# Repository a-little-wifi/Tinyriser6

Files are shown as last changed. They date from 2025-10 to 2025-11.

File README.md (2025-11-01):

# Tinyriser Hex (Tinyriser6)
Tinyriser for the Tiny6 and Tiny7 generation of Lenovo Tiny PCs
Same idea as [the original Tinyriser](https://github.com/a-little-wifi/Tinyriser), but for the next gen.  
Compatible with M90q gen 1 & 2, P340 and P350 Tiny (M70q and M80q don't have the riser slot populated)

## Features:

- PCIe x16 slot (8 lanes from CPU)
- M.2 M-key NVMe slot (4 lanes from PCH)
- USB 2.0 port
- Fan header
- Other random riser slot IO breakout (for science)
- Plug and play, no mainboard modification necessary

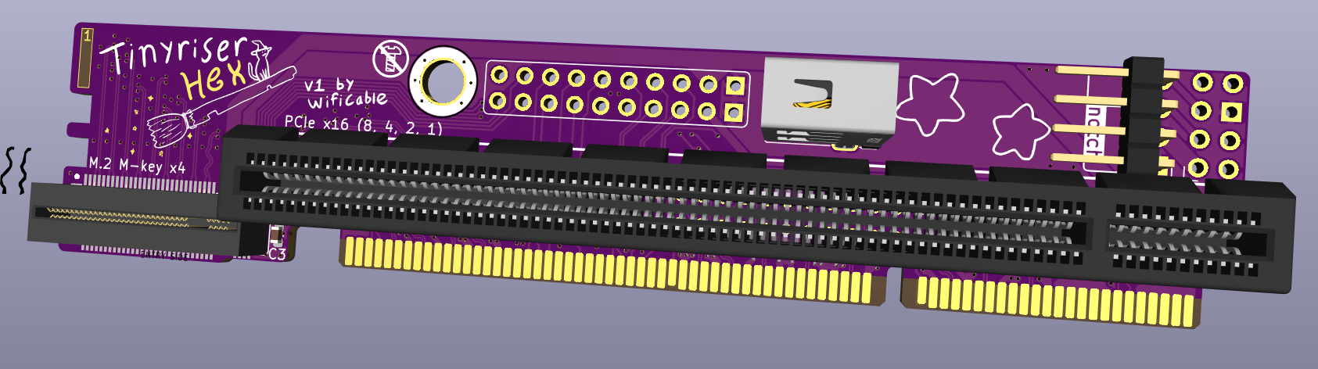
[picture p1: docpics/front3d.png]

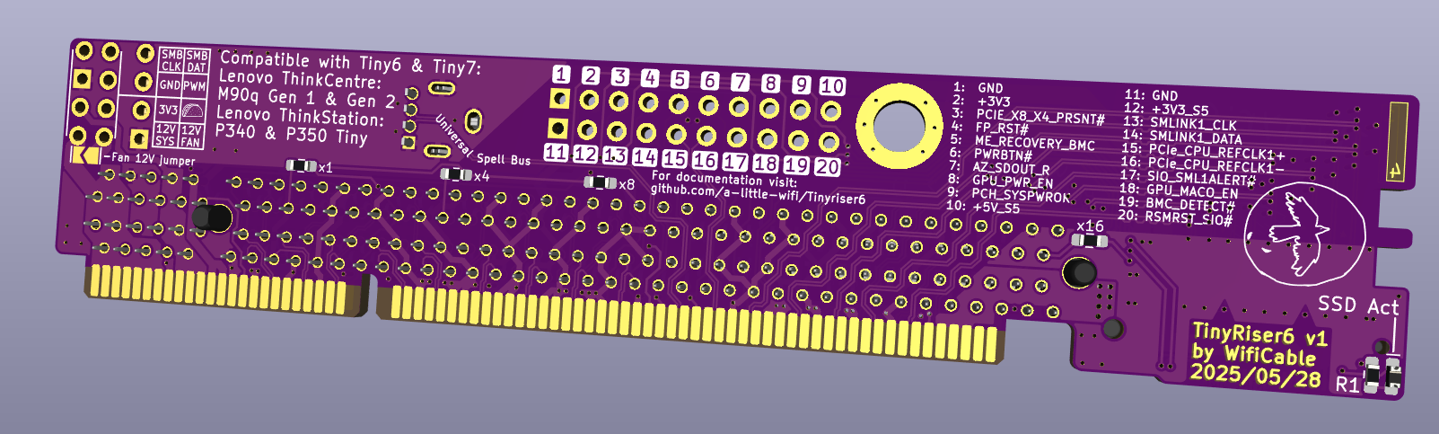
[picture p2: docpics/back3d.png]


> front and back in 3D render  

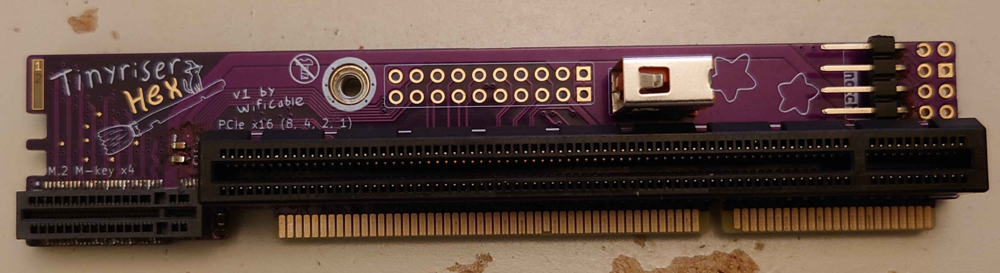
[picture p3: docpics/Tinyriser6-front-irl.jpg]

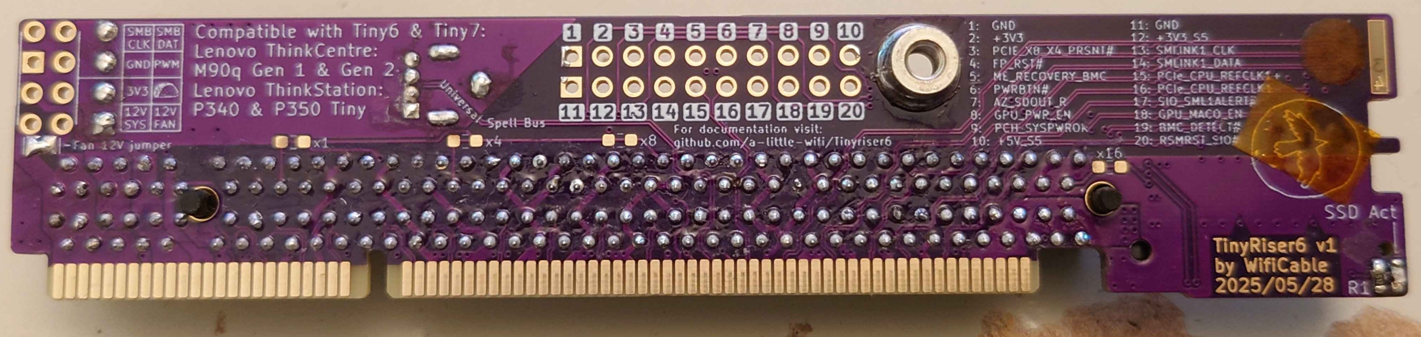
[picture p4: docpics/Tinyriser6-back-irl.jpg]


> front and back in real life

This riser gives you access to the PCIe x8 link from the CPU and the PCIe x4 link from the PCH at the same time, in the form of a PCIe x16 (physical) slot and an M.2 M-key slot.  
Also has a USB 2.0 port because the riser slot has it so why not.  
It does not require any modification to the motherboard of the host machine, just plug and play.  

Using this riser, you can install a low profile PCIe card just as you can with the stock risers, and add an extra M.2 NVMe SSD in addition to the onboard ones. The SSD is tucked away near the front of the machine, plugged into a right angle M-key M.2 slot that holds the SSD firmly in place.  
M.2 2280 length SSDs might have some trouble fitting, especially in combination with longer PCIe cards as they run into the fan and speaker connector on the motherboard. I leave it up to the individual to judge what will be a good fit.  

I've successfully tested this design in P340 (Tiny6) and P350 (Tiny7) machines. Both PCIe links with all lanes as well as the USB port are fully functional in both of them.  

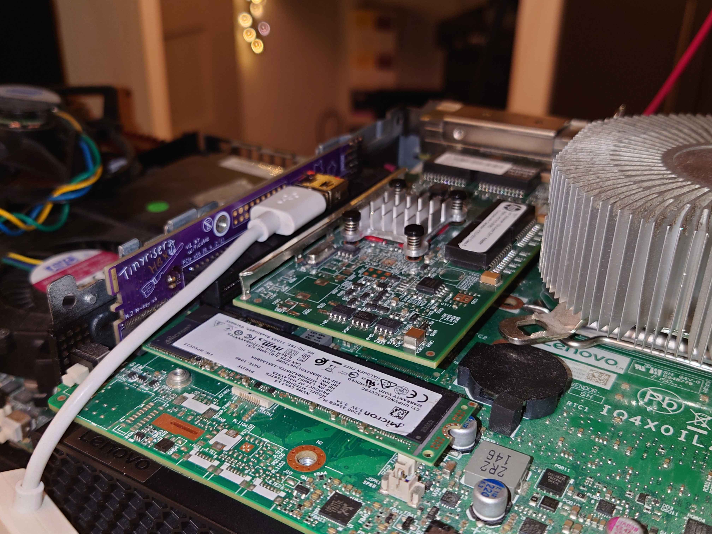
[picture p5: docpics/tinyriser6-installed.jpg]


> riser installed in a P340 with PCIe card, SSD and USB cable attached

### Fan header:
The fan header has the same 3 modes as on the original Tinyriser:
- 12V no PWM
- 12V with PWM
- Voltage controlled speed

The last 2 modes require some kind of fan controller module plugged into the provided header. This has not been designed yet, but the possibility exists.

**Update: v1.1 now has a '5V no PWM' mode available as well, adding an extra jumper from the 5V rail instead of the 12V rail. This 5V rail is always on though, so the fan would be powered even when the system is turned off.**  
**Also be careful when soldering the 5V jumper, it's really close to a 12V pin from the PCIe slot.**

## Thank you

I want to say thank you to everyone for the kind words about my first riser design, I never expected it to reach so far and get so much interest. I originally made it just because I wanted to know if it would work and because I needed a riser for my M720q anyway (would you believe I don't own or have even ever seen a stock Lenovo Tiny5 riser?).  
The experience has had its ups and downs, it turned out I was nowhere near prepared to be handling sales, there's been a few people trying to take credit for my work, and life has been throwing one thing after the other at me, there've been many times I felt bad about it (sorry for the occasional blunt or delayed replies), but in the end I'm still glad I could put it out there and that people have been able to enjoy it. I've even had people reach out suggesting different riser versions and requesting assistance with making modified designs, that's what I love to see. I hope the same will go for this one.

So really, thank you to everyone who has expressed their appreciation for my work, and maybe even bought one from me directly during the short time that was possible. Your support really fills my little wifi heart with motivation to continue making my silly pieces of PCB art in my own way. I hope to keep delving into the depths of modern PC hardware architecture and to deliver more high quality designs with some soul of their own in the future.

This design is the result of everything I've learned from my experience with the original Tinyariser and more. It includes an improved edge connector design that better follows industry standards, a short-circuit discouragement pictogram, several hidden cats, silly puns and more magic.

### Made with ❤ and ✨ by Wifi. I poured my heart, soul and passion into this, I hope you love it too!

## Parts list: 
| part | model | link |
|---|---|---|
| PCIe slot | UMAX 3183-10203P1T | https://www.lcsc.com/product-detail/Card-Edge-Connectors_UMAX-3183-10203P1T_C404116.html |
| Vertical M-key slot | Lotes APCI0110-P001A | (available on aliexpress) |
| Alt M-key slot | HOAUC HYCW19M-05NGFF-530B | https://jlcpcb.com/partdetail/HOAUC-HYCW19M_05NGFF530B/C41430861 (out of stock, but should work with JLC assmebly?) |
| Screwpost | YIYUAN SMTSOM340BTR | https://www.lcsc.com/product-detail/Other-nuts_YIYUAN-SMTSOM340BTR_C5301786.html |
| USB port | Jing 906-862A1118D10200 | https://www.lcsc.com/product-detail/C2763236.html (Warning: EasyEDA footprint pinout is reversed)|

## JLC PCB ordering details:

Please use the files from the v1 release, the main repo might be in the middle of version changes

You're welcome to place your own group orders if you know enough people who are interested in getting one of these risers, however please leave actual selling of this riser design to me and people I've specifically made agreements with.

### Order it in purple Ò̶̖͗̅Ŕ̵͈ ̴̠̬̝̚E̷̖̘̐́̿L̴̢͉̠̕͝S̵͖̺̰̋̀Ē̶̫̾ͅ

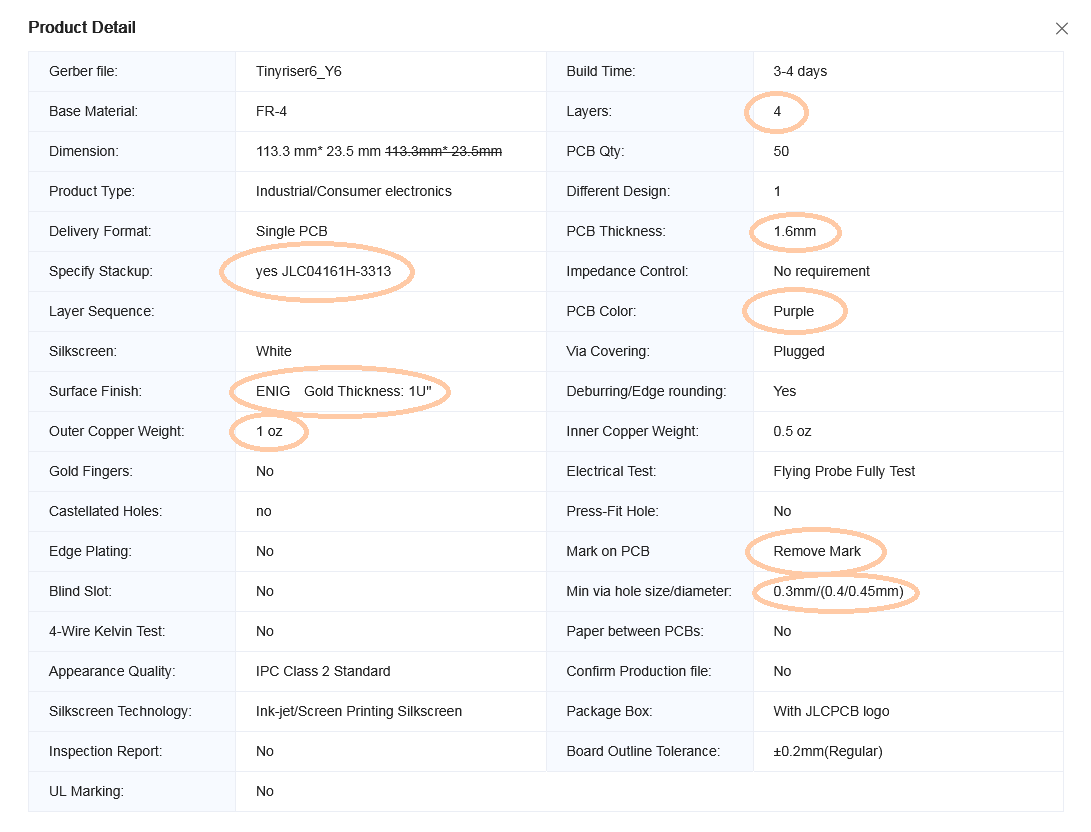
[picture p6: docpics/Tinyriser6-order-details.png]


> Screenshot of the JLC PCB order settings used for Tinyriser6

# Attribution
If you distribute this design or use this design to create a derivative design, you must keep attribution to this original design, in addition to following the terms in the license

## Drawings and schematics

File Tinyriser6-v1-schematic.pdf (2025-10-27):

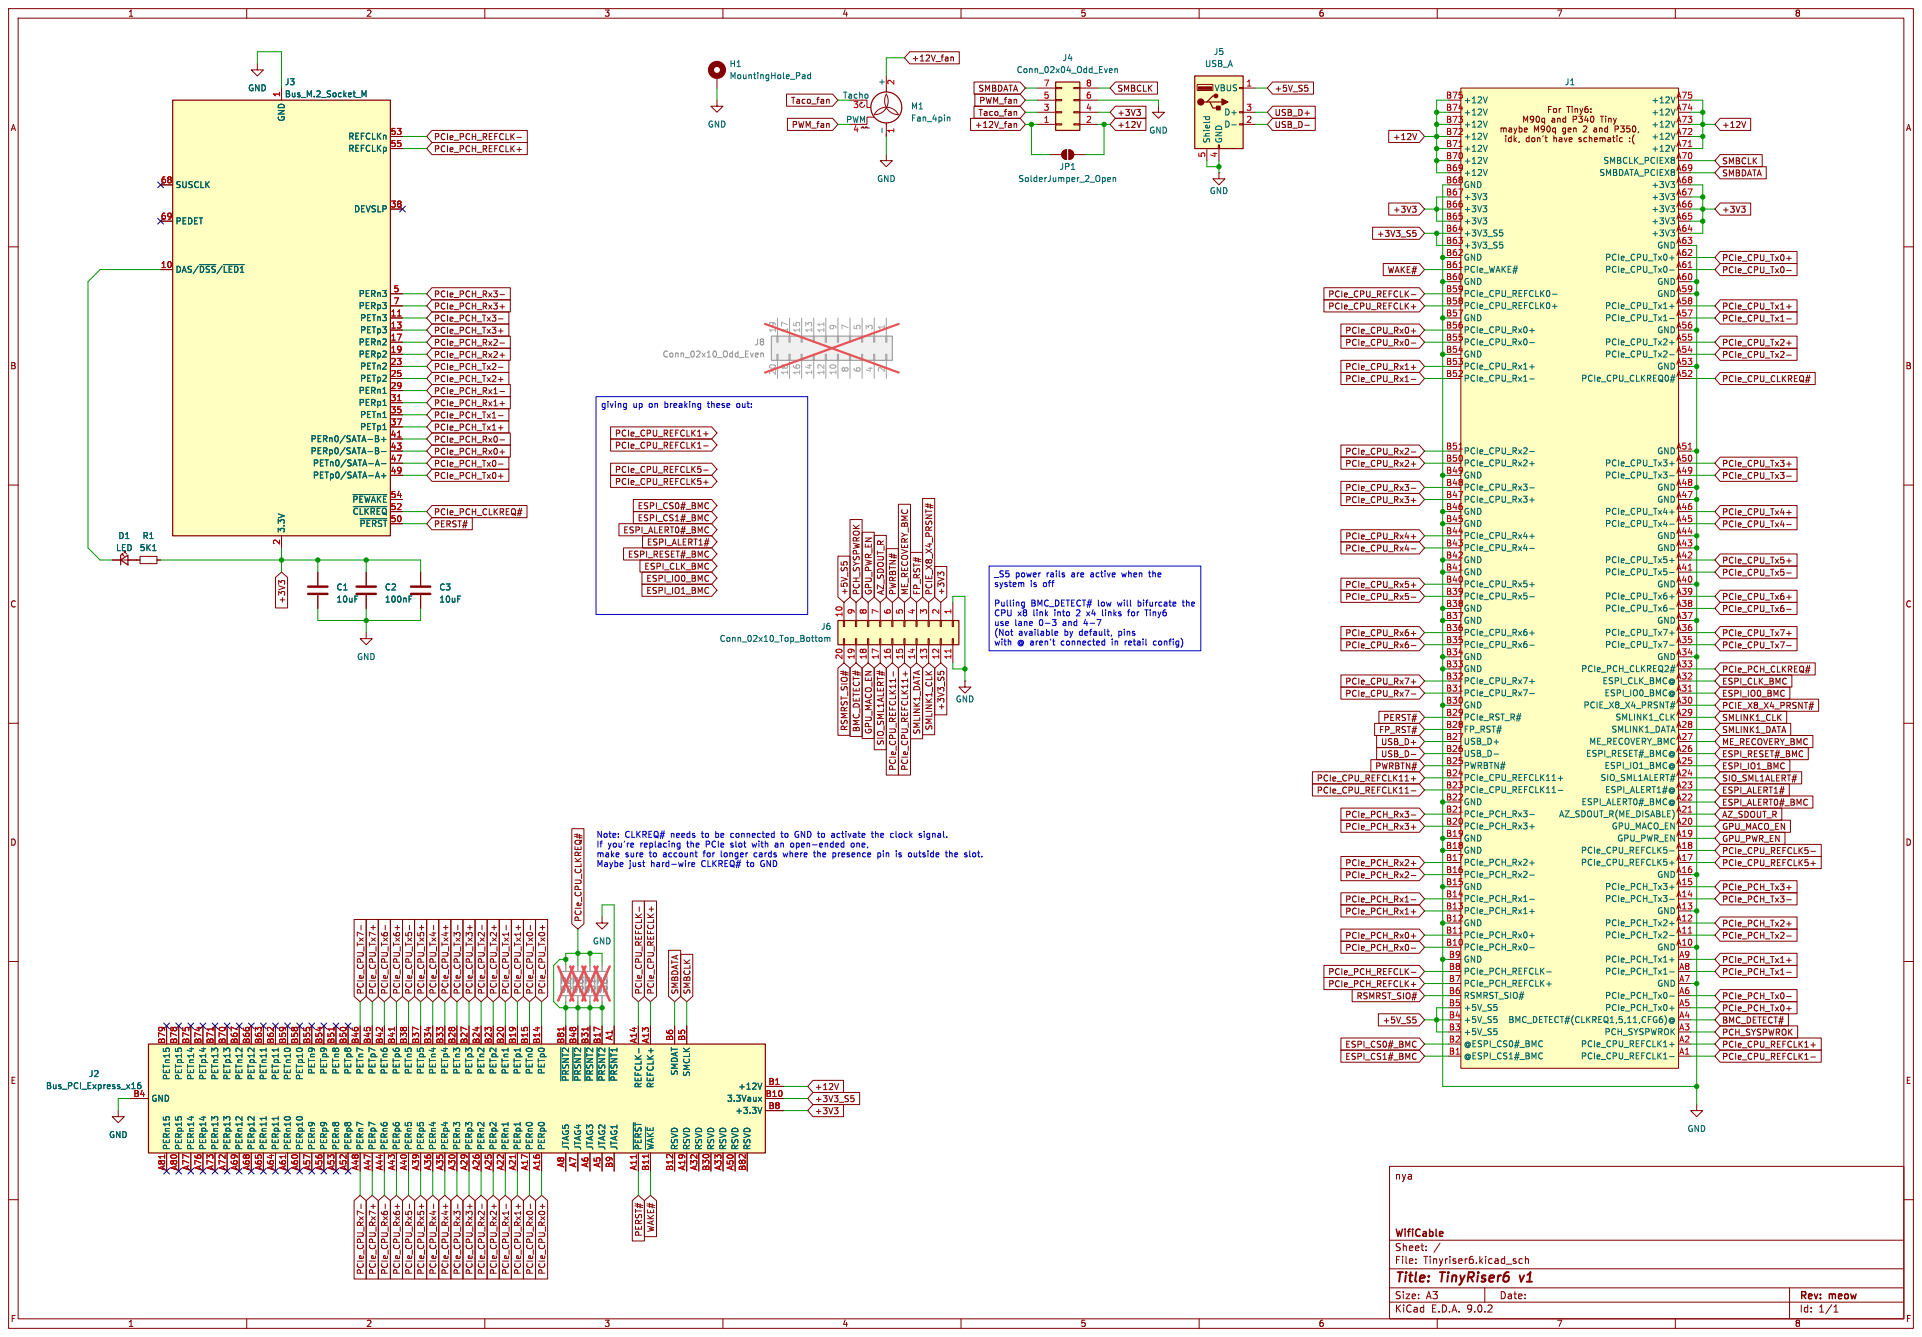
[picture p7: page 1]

1 DAS/~{DSS}/~{LED1} 10 PEDET 69 SUSCLK 68 GND

1 DAS/~{DSS}/~{LED1} 10 PEDET 69 SUSCLK 68

GND SMCLK B5 SMDAT B6 REFCLK+ A13 REFCLK- A14 ~{PRSNT1}A1 ~{PRSNT2}B17 ~{PRSNT2}B31 ~{PRSNT2}B48 ~{PRSNT2}B81 PETp0 B14 PETn0 B15 PETp1 B19 PETn1 B20 PETp2 B23 PETn2 B24 PETp3 B27 PETn3 B28 PETp4 B33 PETn4 B34 PETp5 B37 PETn5 B38 PETp6 B41 PETn6 B42 PETp7 B45 PETn7 B46 PETp8 B50 PETn8 B51 PETp9 B54 PETn9 B55 PETp10 B58 PETn10 B59 PETp11 B62 PETn11 B63 PETp12 B66 PETn12 B67 PETp13 B70 PETn13 B71 PETp14 B74 PETn14 B75 PETp15 B78 PETn15 B79

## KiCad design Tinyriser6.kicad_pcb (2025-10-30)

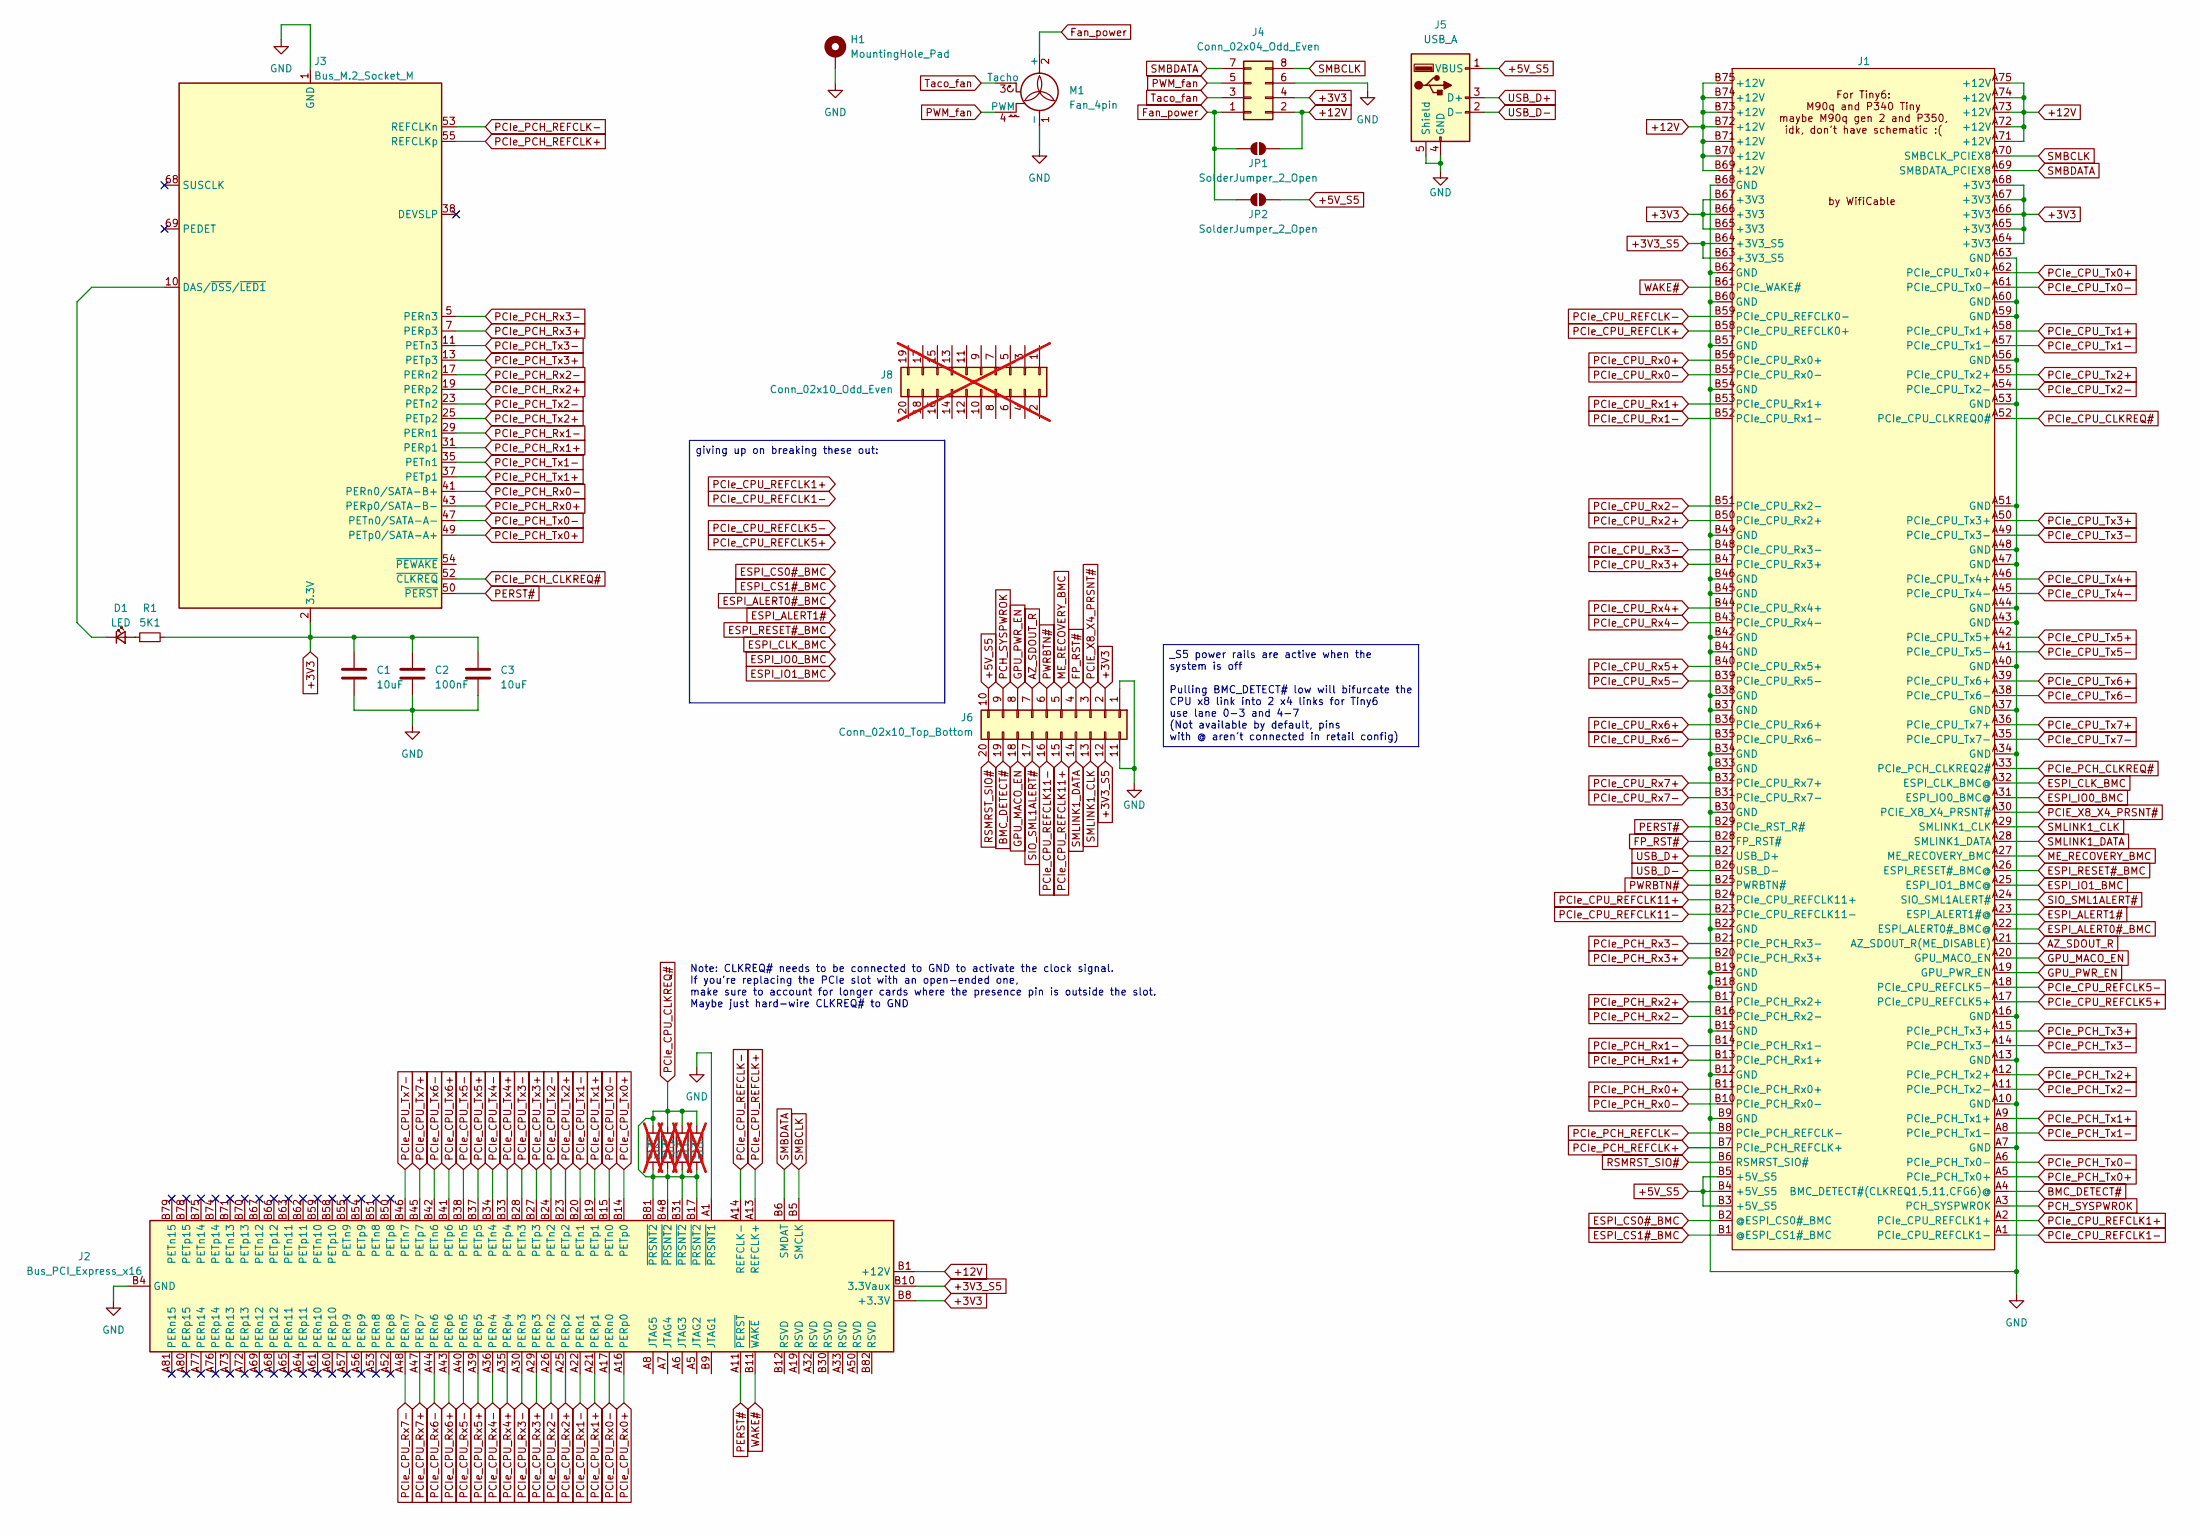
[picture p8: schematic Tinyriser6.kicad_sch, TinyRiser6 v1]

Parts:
C1, C3: 10uF; C_0603_1608Metric
C2: 100nF; C_0603_1608Metric
D1: LED; D_0603_1608Metric_Pad1.05x0.95mm_HandSolder
H1: MountingHole_Pad; MountingHole_4.3mm_M4_ISO7380_Pad_TopOnly
J1: TinyRiser6
J2: Bus_PCI_Express_x16; PCIe_x16_tht_smallholes
J3: Bus_M.2_Socket_M; M.2_NGFF_KeyM_H5.3_Vertical
J4: Conn_02x04_Odd_Even; PinSocket_2x04_P2.54mm_Horizontal
J5: USB_A; that-sideways-usb
J6: Conn_02x10_Top_Bottom; PinHeader_2x10_P2.54mm_Vertical
J8: Conn_02x10_Odd_Even; PinHeader_2x10_P2.54mm_Vertical; not fitted
JP1, JP2: SolderJumper_2_Open; SolderJumper-2_P1.3mm_Open_TrianglePad1.0x1.5mm
M1: Fan_4pin; PinHeader_1x04_P2.54mm_Horizontal
R1: 5K1; R_0603_1608Metric_Pad0.98x0.95mm_HandSolder
R2, R3, R4, R5: 0R; R_0603_1608Metric_Pad0.98x0.95mm_HandSolder; not fitted

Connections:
+3V3: C1.1, C2.1, C3.1, J1.A64 (+3V3), J1.A65 (+3V3), J1.A66 (+3V3), J1.A67 (+3V3), J1.A68 (+3V3), J1.B65 (+3V3), J1.B66 (+3V3), J1.B67 (+3V3), J2.A9 (+3.3V), J2.A10 (+3.3V), J2.B8 (+3.3V), J3.2 (3.3V), J3.4 (3.3V), J3.12 (3.3V), J3.14 (3.3V), J3.16 (3.3V), J3.18 (3.3V), J3.70 (3.3V), J3.72 (3.3V), J3.74 (3.3V), J4.4, J6.2, R1.2
+3V3_S5: J1.B63 (+3V3_S5), J1.B64 (+3V3_S5), J2.B10 (3.3Vaux), J6.12
+5V_S5: J1.B3 (+5V_S5), J1.B4 (+5V_S5), J1.B5 (+5V_S5), J5.1 (VBUS), J6.10, JP2.2 (B)
+12V: J1.A71 (+12V), J1.A72 (+12V), J1.A73 (+12V), J1.A74 (+12V), J1.A75 (+12V), J1.B69 (+12V), J1.B70 (+12V), J1.B71 (+12V), J1.B72 (+12V), J1.B73 (+12V), J1.B74 (+12V), J1.B75 (+12V), J2.A2 (+12V), J2.A3 (+12V), J2.B1 (+12V), J2.B2 (+12V), J2.B3 (+12V), J4.2, JP1.2 (B)
AZ_SDOUT_R: J1.A21 (AZ_SDOUT_R(ME_DISABLE)), J6.7
BMC_DETECT#: J1.A4 (BMC_DETECT#(CLKREQ1,5,11,CFG6)@), J6.19
ESPI_ALERT0#_BMC: J1.A22 (ESPI_ALERT0#_BMC@)
ESPI_ALERT1#: J1.A23 (ESPI_ALERT1#@)
ESPI_CLK_BMC: J1.A32 (ESPI_CLK_BMC@)
ESPI_CS0#_BMC: J1.B2 (@ESPI_CS0#_BMC)
ESPI_CS1#_BMC: J1.B1 (@ESPI_CS1#_BMC)
ESPI_IO0_BMC: J1.A31 (ESPI_IO0_BMC@)
ESPI_IO1_BMC: J1.A25 (ESPI_IO1_BMC@)
ESPI_RESET#_BMC: J1.A26 (ESPI_RESET#_BMC@)
FP_RST#: J1.B28 (FP_RST#), J6.4
Fan_power: J4.1, JP1.1 (A), JP2.1 (A), M1.2 (+)
GND: C1.2, C2.2, C3.2, H1.1, J1.A7 (GND), J1.A10 (GND), J1.A13 (GND), J1.A16 (GND), J1.A34 (GND), J1.A37 (GND), J1.A40 (GND), J1.A43 (GND), J1.A44 (GND), J1.A47 (GND), J1.A48 (GND), J1.A51 (GND), J1.A53 (GND), J1.A56 (GND), J1.A59 (GND), J1.A60 (GND), J1.A63 (GND), J1.B9 (GND), J1.B12 (GND), J1.B15 (GND), J1.B18 (GND), J1.B19 (GND), J1.B22 (GND), J1.B30 (GND), J1.B33 (GND), J1.B34 (GND), J1.B37 (GND), J1.B38 (GND), J1.B41 (GND), J1.B42 (GND), J1.B45 (GND), J1.B46 (GND), J1.B49 (GND), J1.B54 (GND), J1.B57 (GND), J1.B60 (GND), J1.B62 (GND), J1.B68 (GND), J2.A1 (~PRSNT1), J2.A4 (GND), J2.A12 (GND), J2.A15 (GND), J2.A18 (GND), J2.A20 (GND), J2.A23 (GND), J2.A24 (GND), J2.A27 (GND), J2.A28 (GND), J2.A31 (GND), J2.A34 (GND), J2.A37 (GND), J2.A38 (GND), J2.A41 (GND), J2.A42 (GND), J2.A45 (GND), J2.A46 (GND), J2.A49 (GND), J2.A51 (GND), J2.A54 (GND), J2.A55 (GND), J2.A58 (GND), J2.A59 (GND), J2.A62 (GND), J2.A63 (GND), J2.A66 (GND), J2.A67 (GND), J2.A70 (GND), J2.A71 (GND), J2.A74 (GND), J2.A75 (GND), J2.A78 (GND), J2.A79 (GND), J2.A82 (GND), J2.B4 (GND), J2.B7 (GND), J2.B13 (GND), J2.B16 (GND), J2.B18 (GND), J2.B21 (GND), J2.B22 (GND), J2.B25 (GND), J2.B26 (GND), J2.B29 (GND), J2.B32 (GND), J2.B35 (GND), J2.B36 (GND), J2.B39 (GND), J2.B40 (GND), J2.B43 (GND), J2.B44 (GND), J2.B47 (GND), J2.B49 (GND), J2.B52 (GND), J2.B53 (GND), J2.B56 (GND), J2.B57 (GND), J2.B60 (GND), J2.B61 (GND), J2.B64 (GND), J2.B65 (GND), J2.B68 (GND), J2.B69 (GND), J2.B72 (GND), J2.B73 (GND), J2.B76 (GND), J2.B77 (GND), J2.B80 (GND), J3.1 (GND), J3.3 (GND), J3.9 (GND), J3.15 (GND), J3.21 (GND), J3.27 (GND), J3.33 (GND), J3.39 (GND), J3.45 (GND), J3.51 (GND), J3.57 (GND), J3.71 (GND), J3.73 (GND), J3.75 (GND), J4.6, J5.4 (GND), J5.5 (Shield), J6.1, J6.11, M1.1 (-)
GPU_MACO_EN: J1.A20 (GPU_MACO_EN), J6.18
GPU_PWR_EN: J1.A19 (GPU_PWR_EN), J6.8
ME_RECOVERY_BMC: J1.A27 (ME_RECOVERY_BMC), J6.5
unnamed: D1.2 (A), R1.1
unnamed: D1.1 (K), J3.10 (DAS/~DSS/~LED1)
PCH_SYSPWROK: J1.A3 (PCH_SYSPWROK), J6.9
PCIE_X8_X4_PRSNT#: J1.A30 (PCIE_X8_X4_PRSNT#), J6.3
PCIe_CPU_CLKREQ#: J1.A52 (PCIe_CPU_CLKREQ0#), J2.B17 (~PRSNT2), J2.B31 (~PRSNT2), J2.B48 (~PRSNT2), J2.B81 (~PRSNT2), R2.1, R2.2, R3.1, R3.2, R4.1, R4.2, R5.1, R5.2
PCIe_CPU_REFCLK1+: J1.A2 (PCIe_CPU_REFCLK1+)
PCIe_CPU_REFCLK1-: J1.A1 (PCIe_CPU_REFCLK1-)
PCIe_CPU_REFCLK5+: J1.A17 (PCIe_CPU_REFCLK5+)
PCIe_CPU_REFCLK5-: J1.A18 (PCIe_CPU_REFCLK5-)
PCIe_CPU_REFCLK11+: J1.B24 (PCIe_CPU_REFCLK11+), J6.15
PCIe_CPU_REFCLK11-: J1.B23 (PCIe_CPU_REFCLK11-), J6.16
PCIe_CPU_REFCLK+: J1.B58 (PCIe_CPU_REFCLK0+), J2.A13 (REFCLK+)
PCIe_CPU_REFCLK-: J1.B59 (PCIe_CPU_REFCLK0-), J2.A14 (REFCLK-)
PCIe_CPU_Rx0+: J1.B56 (PCIe_CPU_Rx0+), J2.A16 (PERp0)
PCIe_CPU_Rx0-: J1.B55 (PCIe_CPU_Rx0-), J2.A17 (PERn0)
PCIe_CPU_Rx1+: J1.B53 (PCIe_CPU_Rx1+), J2.A21 (PERp1)
PCIe_CPU_Rx1-: J1.B52 (PCIe_CPU_Rx1-), J2.A22 (PERn1)
PCIe_CPU_Rx2+: J1.B50 (PCIe_CPU_Rx2+), J2.A25 (PERp2)
PCIe_CPU_Rx2-: J1.B51 (PCIe_CPU_Rx2-), J2.A26 (PERn2)
PCIe_CPU_Rx3+: J1.B47 (PCIe_CPU_Rx3+), J2.A29 (PERp3)
PCIe_CPU_Rx3-: J1.B48 (PCIe_CPU_Rx3-), J2.A30 (PERn3)
PCIe_CPU_Rx4+: J1.B44 (PCIe_CPU_Rx4+), J2.A35 (PERp4)
PCIe_CPU_Rx4-: J1.B43 (PCIe_CPU_Rx4-), J2.A36 (PERn4)
PCIe_CPU_Rx5+: J1.B40 (PCIe_CPU_Rx5+), J2.A39 (PERp5)
PCIe_CPU_Rx5-: J1.B39 (PCIe_CPU_Rx5-), J2.A40 (PERn5)
PCIe_CPU_Rx6+: J1.B36 (PCIe_CPU_Rx6+), J2.A43 (PERp6)
PCIe_CPU_Rx6-: J1.B35 (PCIe_CPU_Rx6-), J2.A44 (PERn6)
PCIe_CPU_Rx7+: J1.B32 (PCIe_CPU_Rx7+), J2.A47 (PERp7)
PCIe_CPU_Rx7-: J1.B31 (PCIe_CPU_Rx7-), J2.A48 (PERn7)
PCIe_CPU_Tx0+: J1.A62 (PCIe_CPU_Tx0+), J2.B14 (PETp0)
PCIe_CPU_Tx0-: J1.A61 (PCIe_CPU_Tx0-), J2.B15 (PETn0)
PCIe_CPU_Tx1+: J1.A58 (PCIe_CPU_Tx1+), J2.B19 (PETp1)
PCIe_CPU_Tx1-: J1.A57 (PCIe_CPU_Tx1-), J2.B20 (PETn1)
PCIe_CPU_Tx2+: J1.A55 (PCIe_CPU_Tx2+), J2.B23 (PETp2)
PCIe_CPU_Tx2-: J1.A54 (PCIe_CPU_Tx2-), J2.B24 (PETn2)
PCIe_CPU_Tx3+: J1.A50 (PCIe_CPU_Tx3+), J2.B27 (PETp3)
PCIe_CPU_Tx3-: J1.A49 (PCIe_CPU_Tx3-), J2.B28 (PETn3)
PCIe_CPU_Tx4+: J1.A46 (PCIe_CPU_Tx4+), J2.B33 (PETp4)
PCIe_CPU_Tx4-: J1.A45 (PCIe_CPU_Tx4-), J2.B34 (PETn4)
PCIe_CPU_Tx5+: J1.A42 (PCIe_CPU_Tx5+), J2.B37 (PETp5)
PCIe_CPU_Tx5-: J1.A41 (PCIe_CPU_Tx5-), J2.B38 (PETn5)
PCIe_CPU_Tx6+: J1.A39 (PCIe_CPU_Tx6+), J2.B41 (PETp6)
PCIe_CPU_Tx6-: J1.A38 (PCIe_CPU_Tx6-), J2.B42 (PETn6)
PCIe_CPU_Tx7+: J1.A36 (PCIe_CPU_Tx7+), J2.B45 (PETp7)
PCIe_CPU_Tx7-: J1.A35 (PCIe_CPU_Tx7-), J2.B46 (PETn7)
PCIe_PCH_CLKREQ#: J1.A33 (PCIe_PCH_CLKREQ2#), J3.52 (~CLKREQ)
PCIe_PCH_REFCLK+: J1.B7 (PCIe_PCH_REFCLK+), J3.55 (REFCLKp)
PCIe_PCH_REFCLK-: J1.B8 (PCIe_PCH_REFCLK-), J3.53 (REFCLKn)
PCIe_PCH_Rx0+: J1.B11 (PCIe_PCH_Rx0+), J3.43 (PERp0/SATA-B-)
PCIe_PCH_Rx0-: J1.B10 (PCIe_PCH_Rx0-), J3.41 (PERn0/SATA-B+)
PCIe_PCH_Rx1+: J1.B13 (PCIe_PCH_Rx1+), J3.31 (PERp1)
PCIe_PCH_Rx1-: J1.B14 (PCIe_PCH_Rx1-), J3.29 (PERn1)
PCIe_PCH_Rx2+: J1.B17 (PCIe_PCH_Rx2+), J3.19 (PERp2)
PCIe_PCH_Rx2-: J1.B16 (PCIe_PCH_Rx2-), J3.17 (PERn2)
PCIe_PCH_Rx3+: J1.B20 (PCIe_PCH_Rx3+), J3.7 (PERp3)
PCIe_PCH_Rx3-: J1.B21 (PCIe_PCH_Rx3-), J3.5 (PERn3)
PCIe_PCH_Tx0+: J1.A5 (PCIe_PCH_Tx0+), J3.49 (PETp0/SATA-A+)
PCIe_PCH_Tx0-: J1.A6 (PCIe_PCH_Tx0-), J3.47 (PETn0/SATA-A-)
PCIe_PCH_Tx1+: J1.A9 (PCIe_PCH_Tx1+), J3.37 (PETp1)
PCIe_PCH_Tx1-: J1.A8 (PCIe_PCH_Tx1-), J3.35 (PETn1)
PCIe_PCH_Tx2+: J1.A12 (PCIe_PCH_Tx2+), J3.25 (PETp2)
PCIe_PCH_Tx2-: J1.A11 (PCIe_PCH_Tx2-), J3.23 (PETn2)
PCIe_PCH_Tx3+: J1.A15 (PCIe_PCH_Tx3+), J3.13 (PETp3)
PCIe_PCH_Tx3-: J1.A14 (PCIe_PCH_Tx3-), J3.11 (PETn3)
PERST#: J1.B29 (PCIe_RST_R#), J2.A11 (~PERST), J3.50 (~PERST)
PWM_fan: J4.5, M1.4 (PWM)
PWRBTN#: J1.B25 (PWRBTN#), J6.6
RSMRST_SIO#: J1.B6 (RSMRST_SIO#), J6.20
SIO_SML1ALERT#: J1.A24 (SIO_SML1ALERT#), J6.17
SMBCLK: J1.A70 (SMBCLK_PCIEX8), J2.B5 (SMCLK), J4.8
SMBDATA: J1.A69 (SMBDATA_PCIEX8), J2.B6 (SMDAT), J4.7
SMLINK1_CLK: J1.A29 (SMLINK1_CLK), J6.13
SMLINK1_DATA: J1.A28 (SMLINK1_DATA), J6.14
Taco_fan: J4.3, M1.3 (Tacho)
USB_D+: J1.B27 (USB_D+), J5.3 (D+)
USB_D-: J1.B26 (USB_D-), J5.2 (D-)
WAKE#: J1.B61 (PCIe_WAKE#), J2.B11 (~WAKE)

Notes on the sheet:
Note: CLKREQ# needs to be connected to GND to activate the clock signal. If you're replacing the PCIe slot with an open-ended one, make sure to account for longer cards where the presence pin is outside the slot. Maybe just hard-wire CLKREQ# to GND
_S5 power rails are active when the system is off Pulling BMC_DETECT# low will bifurcate the CPU x8 link into 2 x4 links for Tiny6 use lane 0-3 and 4-7 (Not available by default, pins with @ aren't connected in retail config)
giving up on breaking these out:

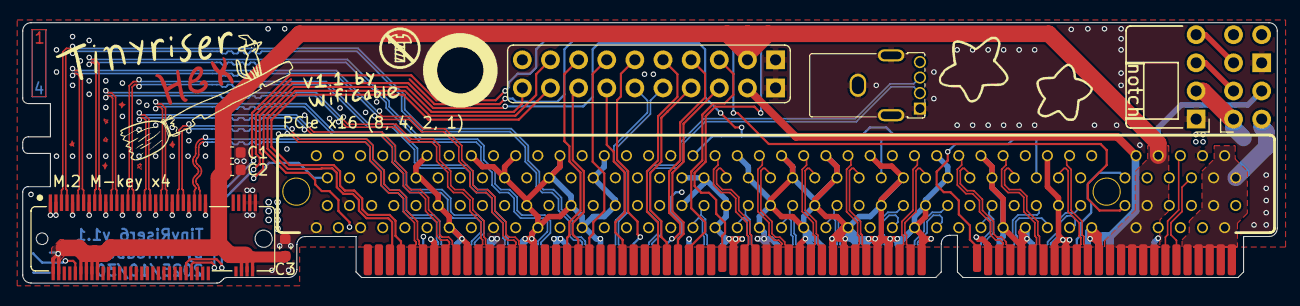
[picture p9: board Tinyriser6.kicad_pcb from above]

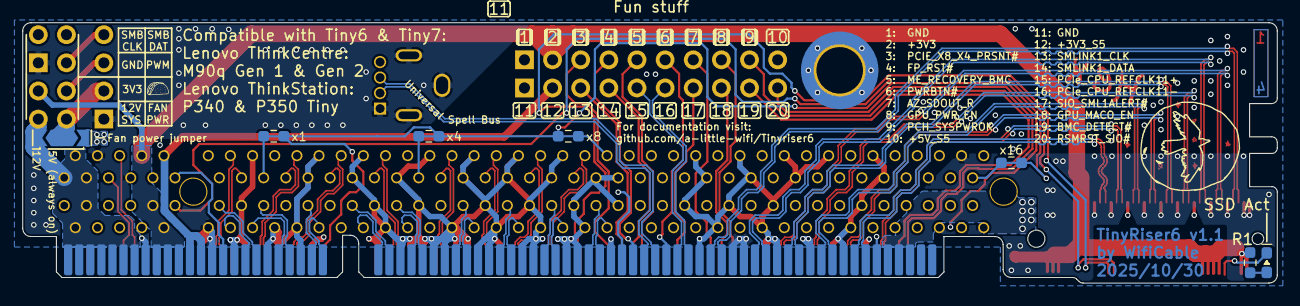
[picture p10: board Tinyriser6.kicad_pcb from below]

Board: 4 copper layers, 113.2 x 23.5 mm, 19 parts (9 on the bottom side), 85 nets.

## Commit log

2024-07-07 Imported a bunch of verified changes from Tiny5 riser v2
    [Tinyriser6.kicad_pcb, Tinyriser6.kicad_sch]
2024-08-05 Updated riser slot info with bifurcation possibility
    [Tinyriser6.kicad_sch]
2024-11-29 Temporarily adding TinyRiser8 symbol for transfer
    [Tinyriser6.kicad_sch]
2025-02-22 carrying over a bunch of stuff from original tinyriser
    [Tinyriser6.kicad_pcb, Tinyriser6.kicad_sch]
2025-02-28 found one more tiny8 pin from beefy riser
    [Tinyriser6.kicad_sch]
2025-03-01 slightly adjusted edge connector footprint dimensions
    [Tinyriser6.kicad_pcb]
2025-03-08 started breaking out all the weird pins
    [Tinyriser6.kicad_sch]
2025-03-08 Added random io header, usb and started routing M.2 PCIe
    [Tinyriser6.kicad_pcb, Tinyriser6.kicad_sch]
2025-03-08 Finished routing M.2 PCIe lanes
    [Tinyriser6.kicad_pcb]
2025-03-08 routed power and some misc signals
    [Tinyriser6.kicad_pcb]
2025-03-08 wired up fan header
    [Tinyriser6.kicad_pcb]
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2025-03-12 Trying to figure out what to do with the random io
    [Tinyriser6.kicad_pcb, Tinyriser6.kicad_sch]
2025-03-15 changed usb port, testing new logo placement
    [Tinyriser6.kicad_pcb, Tinyriser6.kicad_sch]
2025-03-16 giving up on some random IO pins
    [Tinyriser6.kicad_pcb, Tinyriser6.kicad_sch]
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2025-03-16 Moved PCIe slot down 0.25mm
    [Tinyriser6.kicad_pcb]
2025-03-16 wired up ssd led
    [Tinyriser6.kicad_pcb]
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2025-03-16 giving up on breaking out ESPI, tuned some diffpairs
    [Tinyriser6.kicad_pcb, Tinyriser6.kicad_sch]
2025-03-16 Changed misc IO header to 2x10 and started routing it
    [Tinyriser6.kicad_pcb, Tinyriser6.kicad_sch]
2025-03-16 routed misc m.2 signals and mostly routed misc IO header
    [Tinyriser6.kicad_pcb, Tinyriser6.kicad_sch]
2025-03-16 made misc IO traces prettier
    [Tinyriser6.kicad_pcb]
2025-03-16 routed misc io header power pins
    [Tinyriser6.kicad_pcb]
2025-03-17 Added fill to break out 5V
    [Tinyriser6.kicad_pcb]
2025-03-17 added m.2 slot 3d model
    probably doesn't work on anything but my laptop lol
    [Tinyriser6.kicad_pcb]
2025-03-17 added 3d model for m.2 slot but properly this time
    [Tinyriser6.kicad_pcb]
2025-03-17 fixed 3d model alignment
    [Tinyriser6.kicad_pcb]
2025-03-19 finished connecting pretty much all of the random io
    [Tinyriser6.kicad_pcb, Tinyriser6.kicad_sch]
2025-03-19 UNROUTED 0 LETS GOOOO
    lots of tweaks left to make though :3
    [Tinyriser6.kicad_pcb, Tinyriser6.kicad_sch]
2025-03-20 routed 5V rail properly
    [Tinyriser6.kicad_pcb]
2025-03-20 added ground keepout zones
    [Tinyriser6.kicad_pcb]
2025-03-20 ran some ground, added PCH lane wiggles
    [Tinyriser6.kicad_pcb]
2025-03-20 fixed some layer conflicts
    [Tinyriser6.kicad_pcb]
2025-03-20 saved the fat cat
    [Tinyriser6.kicad_pcb]
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2025-03-20 added soldermask keepout on edge connector and clarified riser slot symbol
    [Tinyriser6.kicad_pcb, Tinyriser6.kicad_sch]
2025-03-20 more ground viassssss
    i wonder if it does pcie 4.0 lol (if someone can figure out how to make tiny7 do that)
    [Tinyriser6.kicad_pcb]
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2025-03-31 little trace nudge
    tiny meaningless thing to commit but i gotta be able to keep the laptops in sync lol
    [Tinyriser6.kicad_pcb]
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2025-04-01 slight gnd via nudge to improve 3.3V rail connection
    [Tinyriser6.kicad_pcb]
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2025-04-04 moved m.2 slot down a little and added clearance for tiny6 bios chip
    [Tinyriser6.kicad_pcb]
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2025-04-06 made some diffpairs a bit nicer
    pcie 4.0 tonight queen 🥺
    [Tinyriser6.kicad_pcb]
2025-04-07 Adjusted edge connector dimensions a bit more
    really glad i grabbed some calipers anyway, it might not have fit otherwise
    [Tinyriser6.kicad_pcb]
2025-04-10 working on changing misc io header to 2.54mm and set m.2 slot to thermal reliefs for handsoldering
    [Tinyriser6.kicad_pcb, Tinyriser6.kicad_sch]
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2025-05-08 Added silkscreen telling you not to put a screw directly into the pcb
    like bruh
    don't do that
    why do all of my risers keep blowing u- 💥
    [Tinyriser6.kicad_pcb]
2025-05-08 Added silkscreen layer to protect from screw damage
    [Tinyriser6.kicad_pcb]
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2025-05-09 unfinished attempt at putting misc io header pinout on silkscreen
    [Tinyriser6.kicad_pcb]
2025-05-14 Changed misc io header pin numbering and added labels for pinout
    [Tinyriser6.kicad_pcb, Tinyriser6.kicad_sch]
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2025-05-16 Todo completed, added date and little easter egg
    [Tinyriser6.kicad_pcb]
2025-05-16 fixed a bunch of things and tweaked some silkscreen
    remember to run DRC, kids
    [Tinyriser6.kicad_pcb]
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2025-05-17 Moved some more vias and traces around to avoid silkscreen
    final version fr this time 💯
    [Tinyriser6.kicad_pcb]
2025-05-17 Updated datecode and fixed keepout clearance
    [Tinyriser6.kicad_pcb]
2025-05-17 didn't label my schematic sheet right smh 😔
    [Tinyriser6.kicad_sch]
2025-05-17 Fixed some net names
    [Tinyriser6.kicad_pcb, Tinyriser6.kicad_sch]
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2025-05-21 Made logo text bigger
    final version fr this time???
    [Tinyriser6.kicad_pcb]
2025-05-21 forgor to rerun fills 😭
    FINAL FR THIS TIME PLEASE
    [Tinyriser6.kicad_pcb]
2025-05-21 removed bacon from edge.cuts and tested gerber export
    [Tinyriser6.kicad_pcb]
2025-05-21 Made screwpost hole 0.1mm smaller
    This is a change from Tinyriser v2.1, not sure how it didn't end up being carried over to this one
    [Tinyriser6.kicad_pcb]
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2025-05-23 post-design-review fixes
    [Tinyriser6.kicad_pcb]
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2025-05-25 forgot to change the date again yesterday
    maybe i shouldn't put the date on the board to-the-day.... prone to messing it up lol
    [Tinyriser6.kicad_pcb]
2025-05-28 Adjusted edge connector dimensions some more
    based on paper prototype, they should be good fr now, I did extra measurements of both the slot and an original riser
    [Tinyriser6.kicad_pcb]
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2025-07-17 small tiny8 symbol updates
    based on official tiny8 x4 riser
    [Tinyriser6.kicad_sch]
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2025-10-28 Fixed refclk number being wrong on silkscreen + updated project to KiCad 9
    How did I miss that all this time... Not worth bumping the version number over though.
    [Tinyriser6.kicad_pcb]
2025-10-30 Some minor adjustments + added 5V option for fan header, bumped version to v1.1
    5V rail is always on though, even when the system is powered off
    [Tinyriser6.kicad_pcb, Tinyriser6.kicad_sch]
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2026-07-26 Fixed broken PERST# trace
    thanks @JoshMartinMaker for spotting it
